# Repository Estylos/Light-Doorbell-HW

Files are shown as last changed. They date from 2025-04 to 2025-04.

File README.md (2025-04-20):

# Light Doorbell Hardware

This repository contains the KiCad design files (schematics and 4-layer circular PCB) for the Light Doorbell prototype: a **battery-powered, LED-signaling doorbell** based on a **STM32L051K8T6** microcontroller and **RFM69HCW** 433 MHz radio module.

A light doorbell is useful in many situations: notifying a user wearing headphones, assisting people with hearing impairments, or simply providing a silent visual alert...

## Overview

The prototype operates both as a transmitter and receiver.  
When the central button is pressed, it sends a coded message to another board listening on the same frequency. Upon receiving the message, the board flashes its dual-color LEDs, green or red, depending on the battery level.

The device is rechargeable via a USB-C connector, and works with a range of several tens of meters in open space.

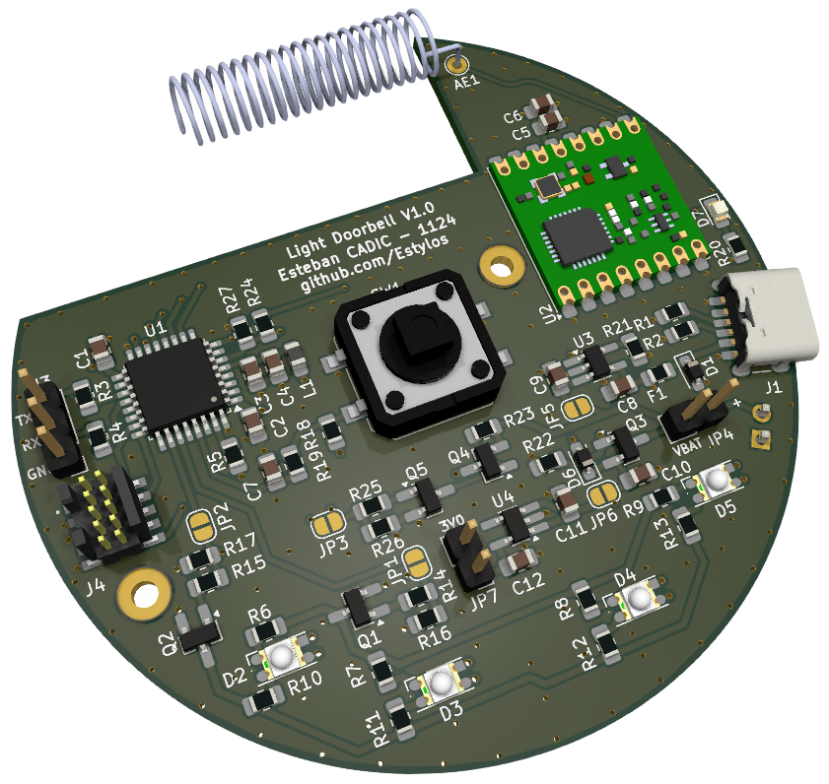
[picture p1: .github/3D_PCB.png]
PCB 3D view


## Features

- **Ultra-low-power STM32L051K8T6** ARM Cortex-M0+, 64 KB Flash, 8 KB RAM
- **RFM69HCW** 433 MHz transceiver module
- **Li-ion / Li-po battery** charger and management IC
- **3.0V LDO voltage regulator** to step down USB or battery voltage
- **Load sharing circuit** to seamlessly switch power source between USB and battery
- **Battery voltage monitoring**
- **433 MHz helical antenna**
- **Dual-color LEDs**, green and red for visual feedback
- **USB-C connector** for charging
- **Large mechanical push-button**
- **10-pin ARM SWD debug / programming port**
- **UART port** for optional serial communication
- **Multiple test points and jumpers** for current measurements, debug, and isolation
- Designed for **hand soldering** and **easy prototyping**
- Optimized for **low power consumption**

The current version focuses on development and testing. A future version could be further miniaturized by removing debug features and using smaller components...

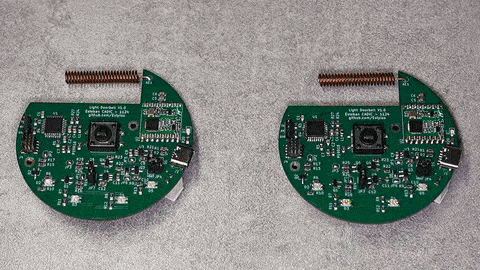
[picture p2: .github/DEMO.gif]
Demo GIF


## Related projects and documentation

- **[Light Doorbell SW](https://github.com/Estylos/Light-Doorbell-SW): Firmware of the project, based on the STM32 CubeHAL**  
- [STM32L051K8T6 Datasheet](https://www.st.com/en/microcontrollers-microprocessors/stm32l051k8.html)  
- [RFM69HCW Datasheet](https://cdn.sparkfun.com/datasheets/Wireless/General/RFM69HCW-V1.1.pdf)  
- [Adafruit Feather M0 Radio with RFM69 Packet Radio](https://learn.adafruit.com/adafruit-feather-m0-radio-with-rfm69-packet-radio/overview)  
- [Microchip (AN1149) - Designing A Li-Ion Battery Charger and Load Sharing System With Microchip’s Stand-Alone Li-Ion Battery Charge Management Controller](https://ww1.microchip.com/downloads/en/appnotes/01149c.pdf)  
- [Zak’s Electronics Blog - A Lithium Battery Charger with Load Sharing.](https://blog.zakkemble.net/a-lithium-battery-charger-with-load-sharing/)  
- [Hackaday - Embed with Elliot: Debounce your Noisy Buttons, Part I.](https://hackaday.com/2015/12/09/embed-with-elliot-debounce-your-noisy-buttons-part-i/)  
- [RefCircruit - Standard Simplest Battery Voltage Monitoring Circuit. ](https://refcircuit.com/articles/854-standard-simplest-battery-voltage-monitoring-circuit-engineering-schematic-solutions.html)

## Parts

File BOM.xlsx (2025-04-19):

Reference | Value | LCSC | Footprint | Description | Datasheet | Qty
AE1 | Antenna | C718844 | PRJ_FOOTPRINTS:THTPad_D2.0mm_Drill1.0mm | Spring Antenna 433 MHz | ~ | 1
C1,C2,C3,C5 | 100n | C1711 | PRJ_FOOTPRINTS:C_0805_2012Metric_Pad1.18x1.45mm_HandSolder | Unpolarized capacitor | ~ | 4
C4,C7,C10,C11 | 1u | C2798196 | PRJ_FOOTPRINTS:C_0805_2012Metric_Pad1.18x1.45mm_HandSolder | Unpolarized capacitor | ~ | 4
C6,C12 | 10u | C17024 | PRJ_FOOTPRINTS:C_0805_2012Metric_Pad1.18x1.45mm_HandSolder | Unpolarized capacitor | ~ | 2
C8,C9 | 4.7u | C1779 | PRJ_FOOTPRINTS:C_0805_2012Metric_Pad1.18x1.45mm_HandSolder | Unpolarized capacitor | ~ | 2
D1 | D_TVS_UNI | C552583 | PRJ_FOOTPRINTS:D_SOD-323_HandSoldering | Uni ESD protection PESD5V0U1UA,115, 6.8V Vbr, IEC61000−4−2 Level 4 | https://assets.nexperia.com/documents/data-sheet/PESD5V0U1UA.pdf | 1
D2,D3,D4,D5 | LED_Dual_Kingbright | C598328 | PRJ_FOOTPRINTS:LED_Kingbright_KPBD-3224 | Dual LED, red, green-yellow, 20°, SMD | https://www.lcsc.com/datasheet/lcsc_datasheet_2008121136_Kingbright-KPBD-3224SURKCGKC_C598328.pdf | 4
D6 | D_Schottky_BAT20JFILM | C155590 | PRJ_FOOTPRINTS:D_SOD-323_HandSoldering | Schottky diode, ST BAT20JFILM, 1A If, 23V Vrrm | https://eu.mouser.com/datasheet/2/389/bat20j-1849045.pdf | 1
D7 | LED | C434431 | PRJ_FOOTPRINTS:LED_0805_2012Metric_Pad1.15x1.40mm_HandSolder | Light emitting diode | ~ | 1
F1 | 0.5A | C2892412 | PRJ_FOOTPRINTS:Fuse_0805_2012Metric_Pad1.15x1.40mm_HandSolder | Fuse 0.5A, KUU K0805L050BR, 0805 | https://www.lcsc.com/datasheet/lcsc_datasheet_2109071730_KUU-K0805L050BR_C2892412.pdf | 1
J1 | USB_C_Receptacle_PowerOnly_6P | C668623 | PRJ_FOOTPRINTS:USB_C_Receptacle_GCT_USB4125-xx-x_6P_TopMnt_Horizontal | USB Power-Only 6P Type-C Receptacle connector | https://www.lcsc.com/datasheet/lcsc_datasheet_2006181823_SHOU-HAN-TYPE-C-6P-073_C668623.pdf | 1
J2 | Conn_01x02_Socket | C131337 | PRJ_FOOTPRINTS:PinHeader_1x02_P2.54mm_Vertical | Generic connector, single row, 01x02, script generated | ~ | 1
J3 | Conn_01x03_Pin |  | PRJ_FOOTPRINTS:PinHeader_1x03_P2.54mm_Vertical | Generic connector, single row, 01x03, script generated | ~ | 1
J4 | Conn_ARM_JTAG_SWD_10 | C448647 | PRJ_FOOTPRINTS:FTSH-105-01-L-DV-K | Cortex Debug Connector, standard ARM Cortex-M SWD and JTAG interface | http://infocenter.arm.com/help/topic/com.arm.doc.ddi0314h/DDI0314H_coresight_components_trm.pdf | 1
JP4,JP7 | Jumper_2_Bridged |  | PRJ_FOOTPRINTS:PinHeader_1x02_P2.54mm_Vertical | Jumper, 2-pole, closed/bridged | ~ | 2
L1 | L_Ferrite | C85835 | PRJ_FOOTPRINTS:L_0805_2012Metric_Pad1.05x1.20mm_HandSolder | Ferrite Beads, 280mΩ ±25%, 1kΩ@100MHz, 0805 | ~ | 1
Q1,Q2,Q5 | IRLML2502TRPBF | C2589 | PRJ_FOOTPRINTS:SOT-23_Handsoldering | N-Channel MOSFET, 20V Vds, 4.2A Id, 45 mΩ Rds(on), SOT-23 | https://www.infineon.com/dgdl/irlml2502pbf-1.pdf?fileId=5546d462533600a4015356680e672608 | 3
Q3,Q4 | IRLML6402TRPBF | C2593 | PRJ_FOOTPRINTS:SOT-23_Handsoldering | P-Channel MOSFET, -20V Vds, -3.7A Id, 65mΩ Rds(on), SOT-23 | https://www.infineon.com/dgdl/irlml6402pbf.pdf?fileId=5546d462533600a401535668d5c2263c | 2
R1,R2 | 5.1k | C2930296 | PRJ_FOOTPRINTS:R_0805_2012Metric_Pad1.20x1.40mm_HandSolder | Resistor | ~ | 2
R3,R4,R14,R15,R20,R25 | 470R | C2907329 | PRJ_FOOTPRINTS:R_0805_2012Metric_Pad1.20x1.40mm_HandSolder | Resistor | ~ | 6
R5,R16,R17,R22,R23,R26 | 100k | C25611 | PRJ_FOOTPRINTS:R_0805_2012Metric_Pad1.20x1.40mm_HandSolder | Resistor | ~ | 6
R6,R7,R8,R9,R10,R11,R12,R13 | 50R | C2828866 | PRJ_FOOTPRINTS:R_0805_2012Metric_Pad1.20x1.40mm_HandSolder | Resistor | ~ | 8
R18,R19,R21,R27 | 10k | C17414 | PRJ_FOOTPRINTS:R_0805_2012Metric_Pad1.20x1.40mm_HandSolder | Resistor | ~ | 4
R24 | 5k | C2828783 | PRJ_FOOTPRINTS:R_0805_2012Metric_Pad1.20x1.40mm_HandSolder | Resistor | ~ | 1
SW1 | SW_Push | C455234 | PRJ_FOOTPRINTS:SW_Push | Push button switch, generic, two pins | https://www.lcsc.com/datasheet/lcsc_datasheet_1912111437_XUNPU-TS-1003ST-26_C455234.pdf | 1
TP_3V0_1,TP_GRN_EN_1,TP_MCU_NRST_1,TP_RADIO_DI0_1,TP_RADIO_RST_1,TP_RED_EN_1,TP_SPI_MISO_1,TP_SPI_MOSI_1,TP_SPI_NSS_1,TP_SPI_SCK_1,TP_VBAT_1,TP_VBAT_ADC_1,TP_VBAT_EN_1,TP_VBUS_1,TP_VCC_1 | TestPoint |  | PRJ_FOOTPRINTS:TestPoint_Pad_D2.0mm | test point | ~ | 15
U1 | STM32L051K8T6 | C915970 | PRJ_FOOTPRINTS:LQFP-32_7x7mm_P0.8mm | STMicroelectronics Arm Cortex-M0+ MCU, 32-64KB flash, 8KB RAM, 32 MHz, 1.65-3.6V, 25 GPIO, LQFP32 | https://eu.mouser.com/datasheet/2/389/stm32l051c6-1851259.pdf | 1
U2 | RFM69HCW |  | PRJ_FOOTPRINTS:HOPERF_RFM9CW_SMD | ISM radio transceiver, SoM | https://cdn.sparkfun.com/datasheets/Wireless/General/RFM69HCW-V1.1.pdf | 1
U3 | MCP73831 | C424093 | PRJ_FOOTPRINTS:TSOT-23-5_HandSoldering | Single cell Li-Ion/Li-Po charge management controller, 4.20V, SOT23-5 | https://ww1.microchip.com/downloads/en/DeviceDoc/MCP73831-Family-Data-Sheet-DS20001984H.pdf | 1
U4 | TPS7A2030PDBVR | C963429 | PRJ_FOOTPRINTS:TSOT-23-5_HandSoldering | LDO Voltage Regulators, 300-mA, ultra-low-noise, low-IQ, SOT23-5 | https://www.ti.com/lit/ds/symlink/tps7a20.pdf | 1

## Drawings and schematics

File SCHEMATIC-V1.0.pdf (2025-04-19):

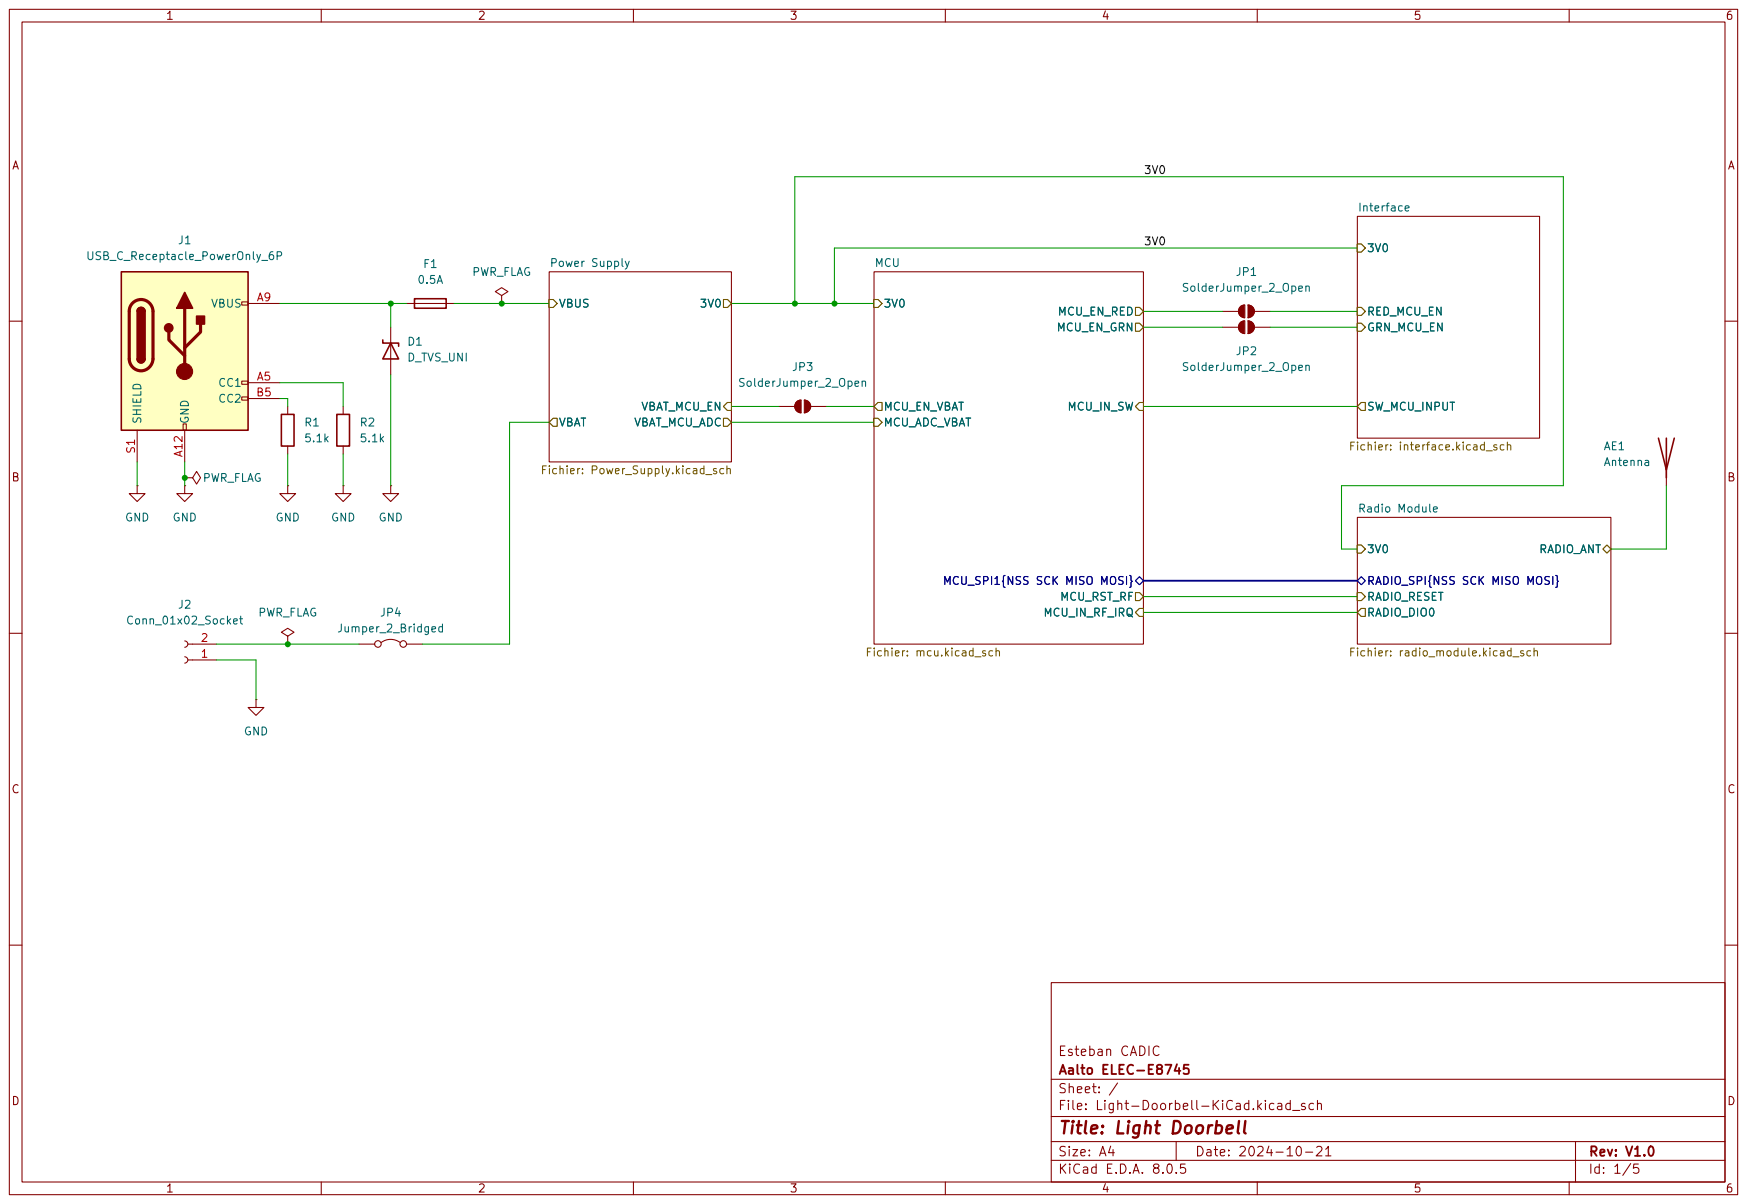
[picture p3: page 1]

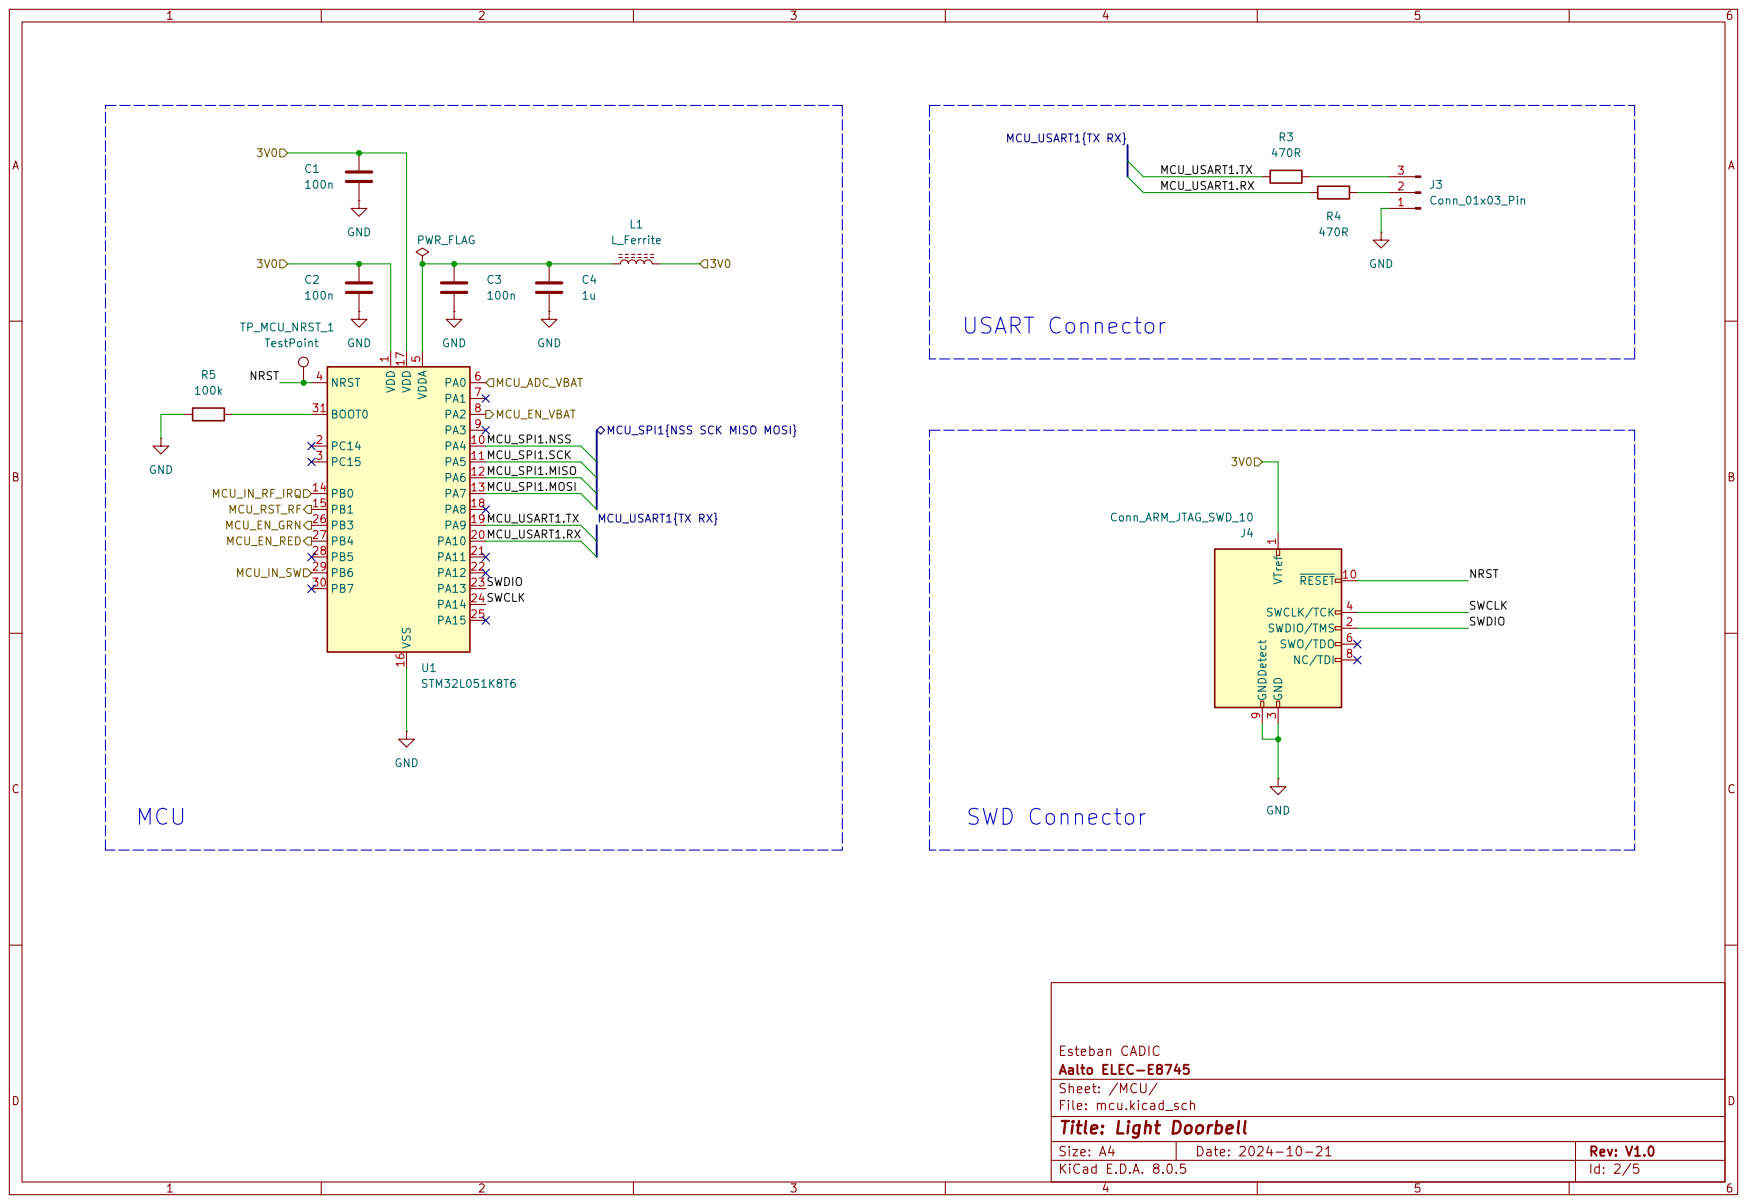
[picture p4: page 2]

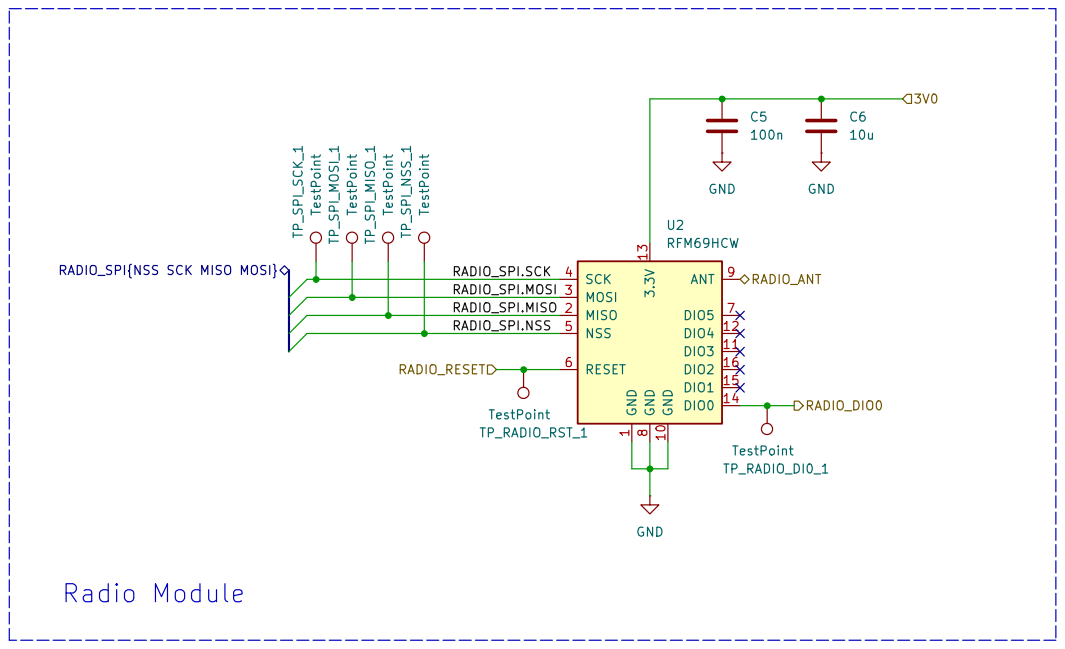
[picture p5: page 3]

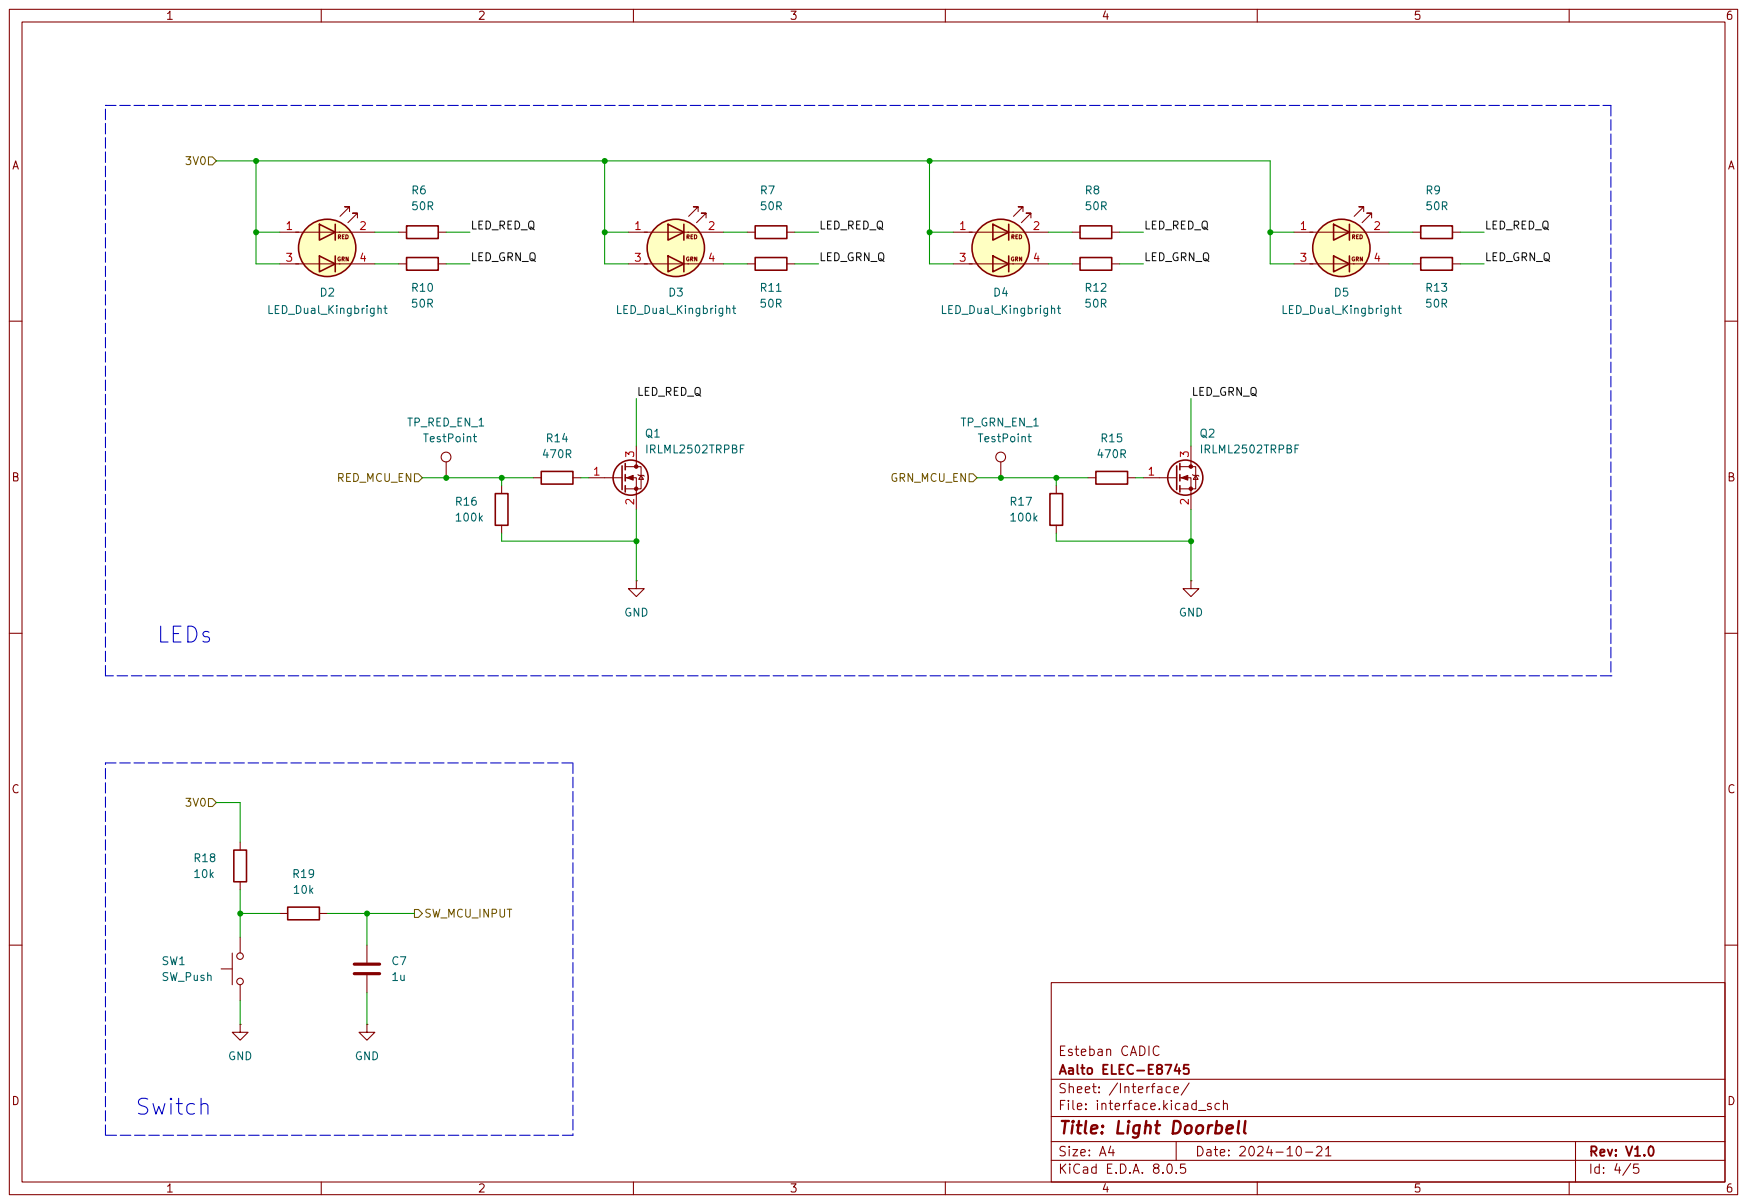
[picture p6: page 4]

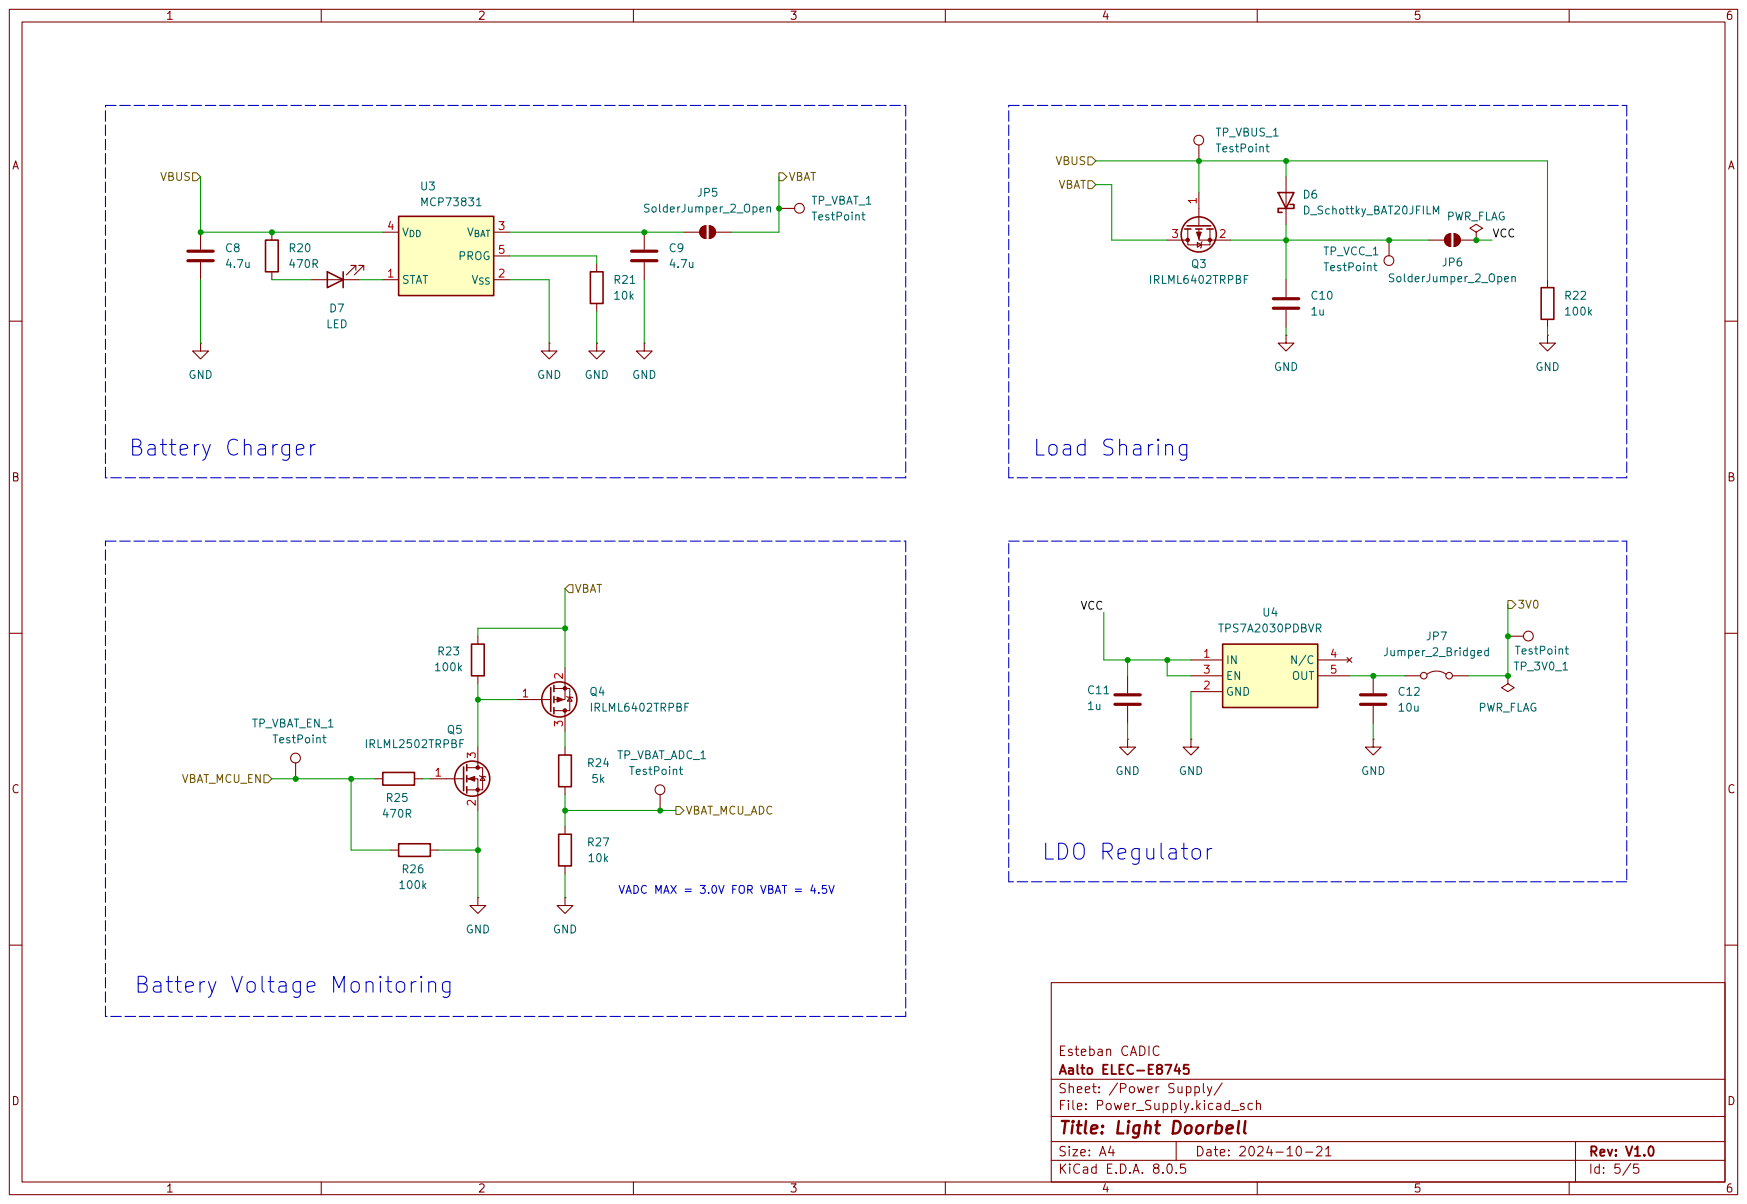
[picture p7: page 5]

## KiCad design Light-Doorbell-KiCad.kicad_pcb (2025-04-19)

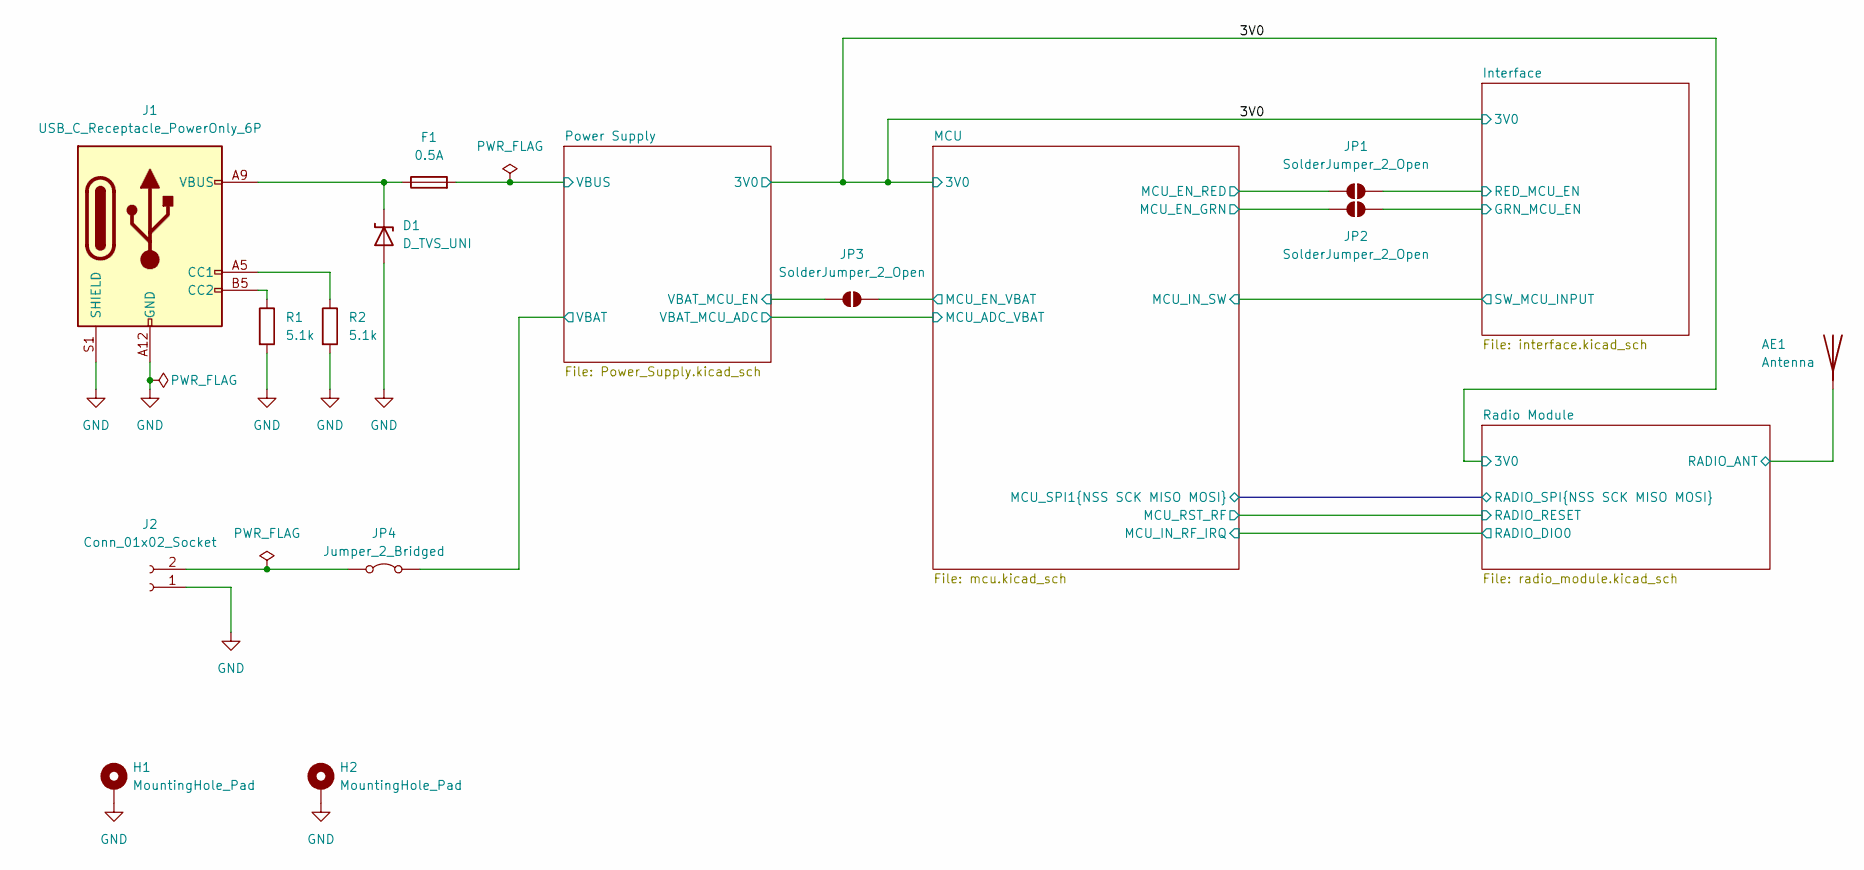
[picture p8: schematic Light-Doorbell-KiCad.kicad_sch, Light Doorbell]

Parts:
AE1: Antenna; THTPad_D2.0mm_Drill1.0mm; LCSC C718844
D1: D_TVS_UNI; D_SOD-323_HandSoldering; LCSC C552583
F1: 0.5A; Fuse_0805_2012Metric_Pad1.15x1.40mm_HandSolder; LCSC C2892412
H1, H2: MountingHole_Pad; MountingHole_2.2mm_M2_Pad
J1: USB_C_Receptacle_PowerOnly_6P; USB_C_Receptacle_GCT_USB4125-xx-x_6P_TopMnt_Horizontal; LCSC C668623
J2: Conn_01x02_Socket; PinHeader_1x02_P2.54mm_Vertical; LCSC C131337
JP1, JP2, JP3: SolderJumper_2_Open; SolderJumper-2_P1.3mm_Open_RoundedPad1.0x1.5mm
JP4: Jumper_2_Bridged; PinHeader_1x02_P2.54mm_Vertical
R1, R2: 5.1k; R_0805_2012Metric_Pad1.20x1.40mm_HandSolder; LCSC C2930296

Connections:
/Interface/GRN_MCU_EN: JP2.2 (B); also elsewhere on the board
/Interface/RED_MCU_EN: JP1.2 (B); also elsewhere on the board
/MCU/MCU_EN_GRN: JP2.1 (A); also elsewhere on the board
/MCU/MCU_EN_RED: JP1.1 (A); also elsewhere on the board
/MCU/MCU_EN_VBAT: JP3.2 (B); also elsewhere on the board
/Power Supply/VBAT: JP4.2 (B); also elsewhere on the board
/Power Supply/VBAT_MCU_EN: JP3.1 (A); also elsewhere on the board
/Power Supply/VBUS: F1.2; also elsewhere on the board
/Radio Module/RADIO_ANT: AE1.1 (A); also elsewhere on the board
GND: D1.2 (A2), H1.1, H2.1, J1.A12 (GND), J1.B12 (GND), J1.S1 (SHIELD), J2.1, R1.2, R2.2; also elsewhere on the board
unnamed: D1.1 (A1), F1.1, J1.A9 (VBUS), J1.B9 (VBUS)
unnamed: J1.A5 (CC1), R2.1
unnamed: J1.B5 (CC2), R1.1
unnamed: J2.2, JP4.1 (A)

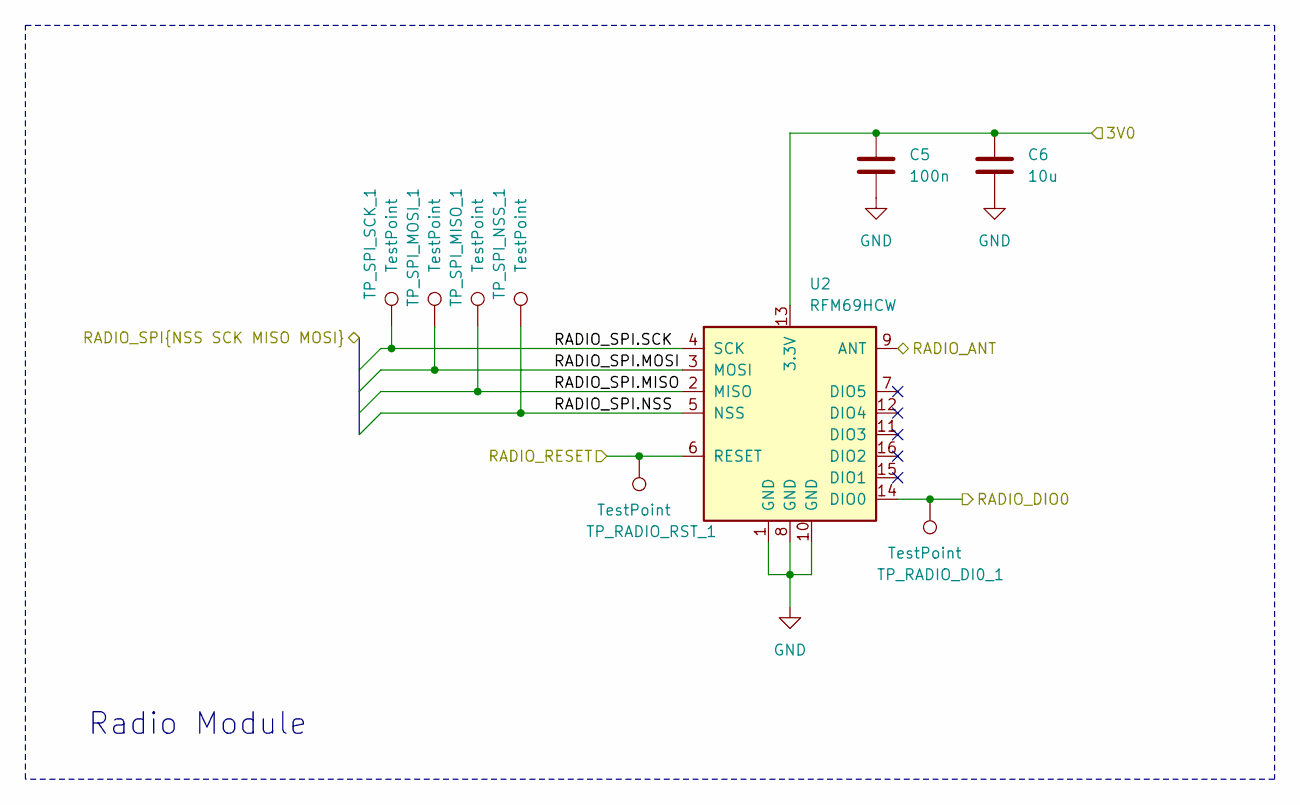
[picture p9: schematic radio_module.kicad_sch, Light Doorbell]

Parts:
C5: 100n; C_0805_2012Metric_Pad1.18x1.45mm_HandSolder; LCSC C1711
C6: 10u; C_0805_2012Metric_Pad1.18x1.45mm_HandSolder; LCSC C17024
TP_RADIO_DI0_1: TestPoint; TestPoint_Pad_D2.0mm
TP_RADIO_RST_1: TestPoint; TestPoint_Pad_D2.0mm
TP_SPI_MISO_1: TestPoint; TestPoint_Pad_D2.0mm
TP_SPI_MOSI_1: TestPoint; TestPoint_Pad_D2.0mm
TP_SPI_NSS_1: TestPoint; TestPoint_Pad_D2.0mm
TP_SPI_SCK_1: TestPoint; TestPoint_Pad_D2.0mm
U2: RFM69HCW; HOPERF_RFM9CW_SMD

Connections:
/3V0: C5.1, C6.1, U2.13 (3.3V); also elsewhere on the board
/MCU/MCU_IN_RF_IRQ: TP_RADIO_DI0_1.1, U2.14 (DIO0); also elsewhere on the board
/MCU/MCU_RST_RF: TP_RADIO_RST_1.1, U2.6 (RESET); also elsewhere on the board
/MCU/MCU_SPI1.MISO: TP_SPI_MISO_1.1, U2.2 (MISO); also elsewhere on the board
/MCU/MCU_SPI1.MOSI: TP_SPI_MOSI_1.1, U2.3 (MOSI); also elsewhere on the board
/MCU/MCU_SPI1.NSS: TP_SPI_NSS_1.1, U2.5 (NSS); also elsewhere on the board
/MCU/MCU_SPI1.SCK: TP_SPI_SCK_1.1, U2.4 (SCK); also elsewhere on the board
/Radio Module/RADIO_ANT: U2.9 (ANT); also elsewhere on the board
GND: C5.2, C6.2, U2.1 (GND), U2.8 (GND), U2.10 (GND); also elsewhere on the board

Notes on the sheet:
Radio Module

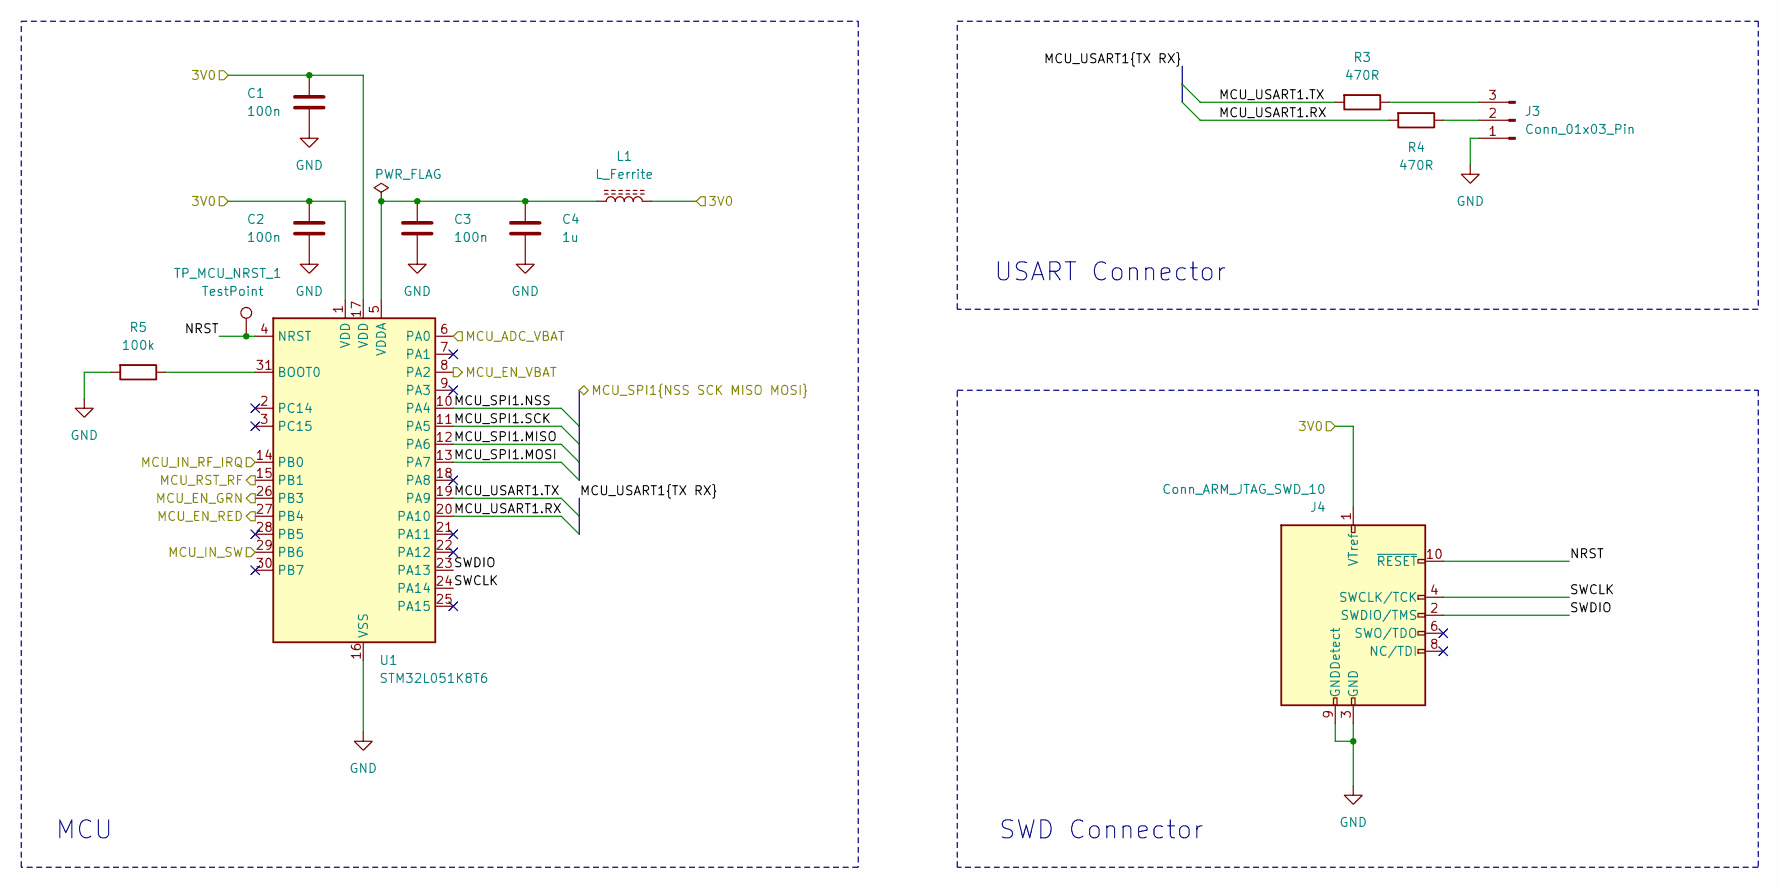
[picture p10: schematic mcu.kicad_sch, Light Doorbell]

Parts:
C1, C2, C3: 100n; C_0805_2012Metric_Pad1.18x1.45mm_HandSolder; LCSC C1711
C4: 1u; C_0805_2012Metric_Pad1.18x1.45mm_HandSolder; LCSC C2798196
J3: Conn_01x03_Pin; PinHeader_1x03_P2.54mm_Vertical
J4: Conn_ARM_JTAG_SWD_10; FTSH-105-01-L-DV-K; LCSC C448647
L1: L_Ferrite; L_0805_2012Metric_Pad1.05x1.20mm_HandSolder; LCSC C85835
R3, R4: 470R; R_0805_2012Metric_Pad1.20x1.40mm_HandSolder; LCSC C2907329
R5: 100k; R_0805_2012Metric_Pad1.20x1.40mm_HandSolder; LCSC C25611
TP_MCU_NRST_1: TestPoint; TestPoint_Pad_D2.0mm
U1: STM32L051K8T6; LQFP-32_7x7mm_P0.8mm; LCSC C915970

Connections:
/3V0: C1.1, C2.1, J4.1 (VTref), L1.2, U1.1 (VDD), U1.17 (VDD); also elsewhere on the board
/Interface/SW_MCU_INPUT: U1.29 (PB6); also elsewhere on the board
/MCU/MCU_ADC_VBAT: U1.6 (PA0); also elsewhere on the board
/MCU/MCU_EN_GRN: U1.26 (PB3); also elsewhere on the board
/MCU/MCU_EN_RED: U1.27 (PB4); also elsewhere on the board
/MCU/MCU_EN_VBAT: U1.8 (PA2); also elsewhere on the board
/MCU/MCU_IN_RF_IRQ: U1.14 (PB0); also elsewhere on the board
/MCU/MCU_RST_RF: U1.15 (PB1); also elsewhere on the board
/MCU/MCU_SPI1.MISO: U1.12 (PA6); also elsewhere on the board
/MCU/MCU_SPI1.MOSI: U1.13 (PA7); also elsewhere on the board
/MCU/MCU_SPI1.NSS: U1.10 (PA4); also elsewhere on the board
/MCU/MCU_SPI1.SCK: U1.11 (PA5); also elsewhere on the board
/MCU/MCU_USART1.RX: R4.2, U1.20 (PA10)
/MCU/MCU_USART1.TX: R3.2, U1.19 (PA9)
/MCU/NRST: J4.10 (~RESET), TP_MCU_NRST_1.1, U1.4 (NRST)
/MCU/SWCLK: J4.4 (SWCLK/TCK), U1.24 (PA14)
/MCU/SWDIO: J4.2 (SWDIO/TMS), U1.23 (PA13)
GND: C1.2, C2.2, C3.2, C4.2, J3.1, J4.3 (GND), J4.5 (GND), J4.9 (GNDDetect), R5.2, U1.16 (VSS), U1.32 (VSS); also elsewhere on the board
unnamed: J3.2, R4.1
unnamed: J3.3, R3.1
unnamed: R5.1, U1.31 (BOOT0)
unnamed: C3.1, C4.1, L1.1, U1.5 (VDDA)

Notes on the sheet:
USART Connector
MCU
SWD Connector

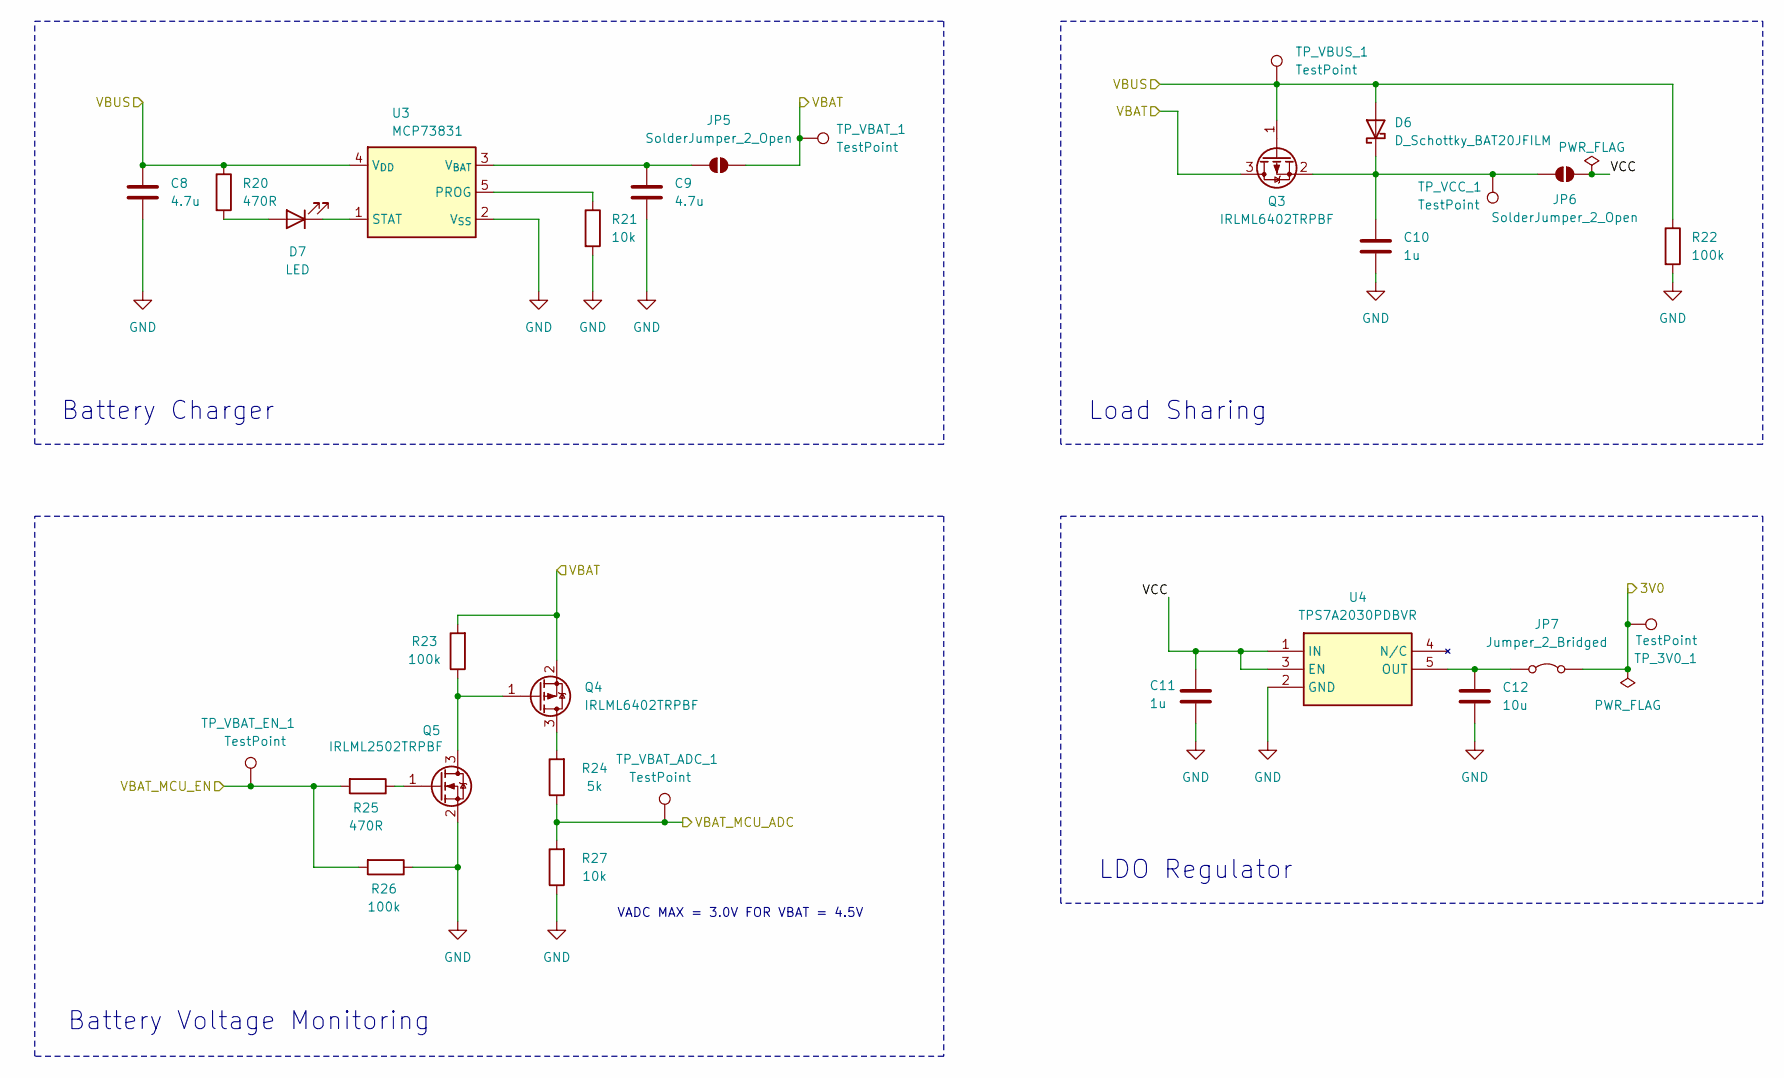
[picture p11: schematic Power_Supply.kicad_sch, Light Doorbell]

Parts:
C8, C9: 4.7u; C_0805_2012Metric_Pad1.18x1.45mm_HandSolder; LCSC C1779
C10, C11: 1u; C_0805_2012Metric_Pad1.18x1.45mm_HandSolder; LCSC C2798196
C12: 10u; C_0805_2012Metric_Pad1.18x1.45mm_HandSolder; LCSC C17024
D6: D_Schottky_BAT20JFILM; D_SOD-323_HandSoldering; LCSC C155590
D7: LED; LED_0805_2012Metric_Pad1.15x1.40mm_HandSolder; LCSC C434431
JP5, JP6: SolderJumper_2_Open; SolderJumper-2_P1.3mm_Open_RoundedPad1.0x1.5mm
JP7: Jumper_2_Bridged; PinHeader_1x02_P2.54mm_Vertical
Q3, Q4: IRLML6402TRPBF; SOT-23_Handsoldering; LCSC C2593
Q5: IRLML2502TRPBF; SOT-23_Handsoldering; LCSC C2589
R20, R25: 470R; R_0805_2012Metric_Pad1.20x1.40mm_HandSolder; LCSC C2907329
R21, R27: 10k; R_0805_2012Metric_Pad1.20x1.40mm_HandSolder; LCSC C17414
R22, R23, R26: 100k; R_0805_2012Metric_Pad1.20x1.40mm_HandSolder; LCSC C25611
R24: 5k; R_0805_2012Metric_Pad1.20x1.40mm_HandSolder; LCSC C2828783
TP_3V0_1: TestPoint; TestPoint_Pad_D2.0mm
TP_VBAT_1: TestPoint; TestPoint_Pad_D2.0mm
TP_VBAT_ADC_1: TestPoint; TestPoint_Pad_D2.0mm
TP_VBAT_EN_1: TestPoint; TestPoint_Pad_D2.0mm
TP_VBUS_1: TestPoint; TestPoint_Pad_D2.0mm
TP_VCC_1: TestPoint; TestPoint_Pad_D2.0mm
U3: MCP73831; TSOT-23-5_HandSoldering; LCSC C424093
U4: TPS7A2030PDBVR; TSOT-23-5_HandSoldering; LCSC C963429

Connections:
/3V0: JP7.2 (B), TP_3V0_1.1; also elsewhere on the board
/MCU/MCU_ADC_VBAT: R24.1, R27.2, TP_VBAT_ADC_1.1; also elsewhere on the board
/Power Supply/VBAT: JP5.2 (B), Q3.3 (D), Q4.2 (S), R23.2, TP_VBAT_1.1; also elsewhere on the board
/Power Supply/VBAT_MCU_EN: R25.2, R26.2, TP_VBAT_EN_1.1; also elsewhere on the board
/Power Supply/VBUS: C8.1, D6.2 (A), Q3.1 (G), R20.1, R22.1, TP_VBUS_1.1, U3.4 (V_{DD}); also elsewhere on the board
/Power Supply/VCC: C11.1, JP6.2 (B), U4.1 (IN), U4.3 (EN)
GND: C8.2, C9.2, C10.2, C11.2, C12.2, Q5.2 (S), R21.2, R22.2, R26.1, R27.1, U3.2 (V_{SS}), U4.2 (GND); also elsewhere on the board
unnamed: C10.1, D6.1 (K), JP6.1 (A), Q3.2 (S), TP_VCC_1.1
unnamed: D7.2 (A), R20.2
unnamed: D7.1 (K), U3.1 (STAT)
unnamed: C9.1, JP5.1 (A), U3.3 (V_{BAT})
unnamed: C12.1, JP7.1 (A), U4.5 (OUT)
unnamed: Q4.3 (D), R24.2
unnamed: Q4.1 (G), Q5.3 (D), R23.1
unnamed: Q5.1 (G), R25.1
unnamed: R21.1, U3.5 (PROG)

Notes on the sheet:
Battery Voltage Monitoring
Load Sharing
Battery Charger
VADC MAX = 3.0V FOR VBAT = 4.5V
LDO Regulator

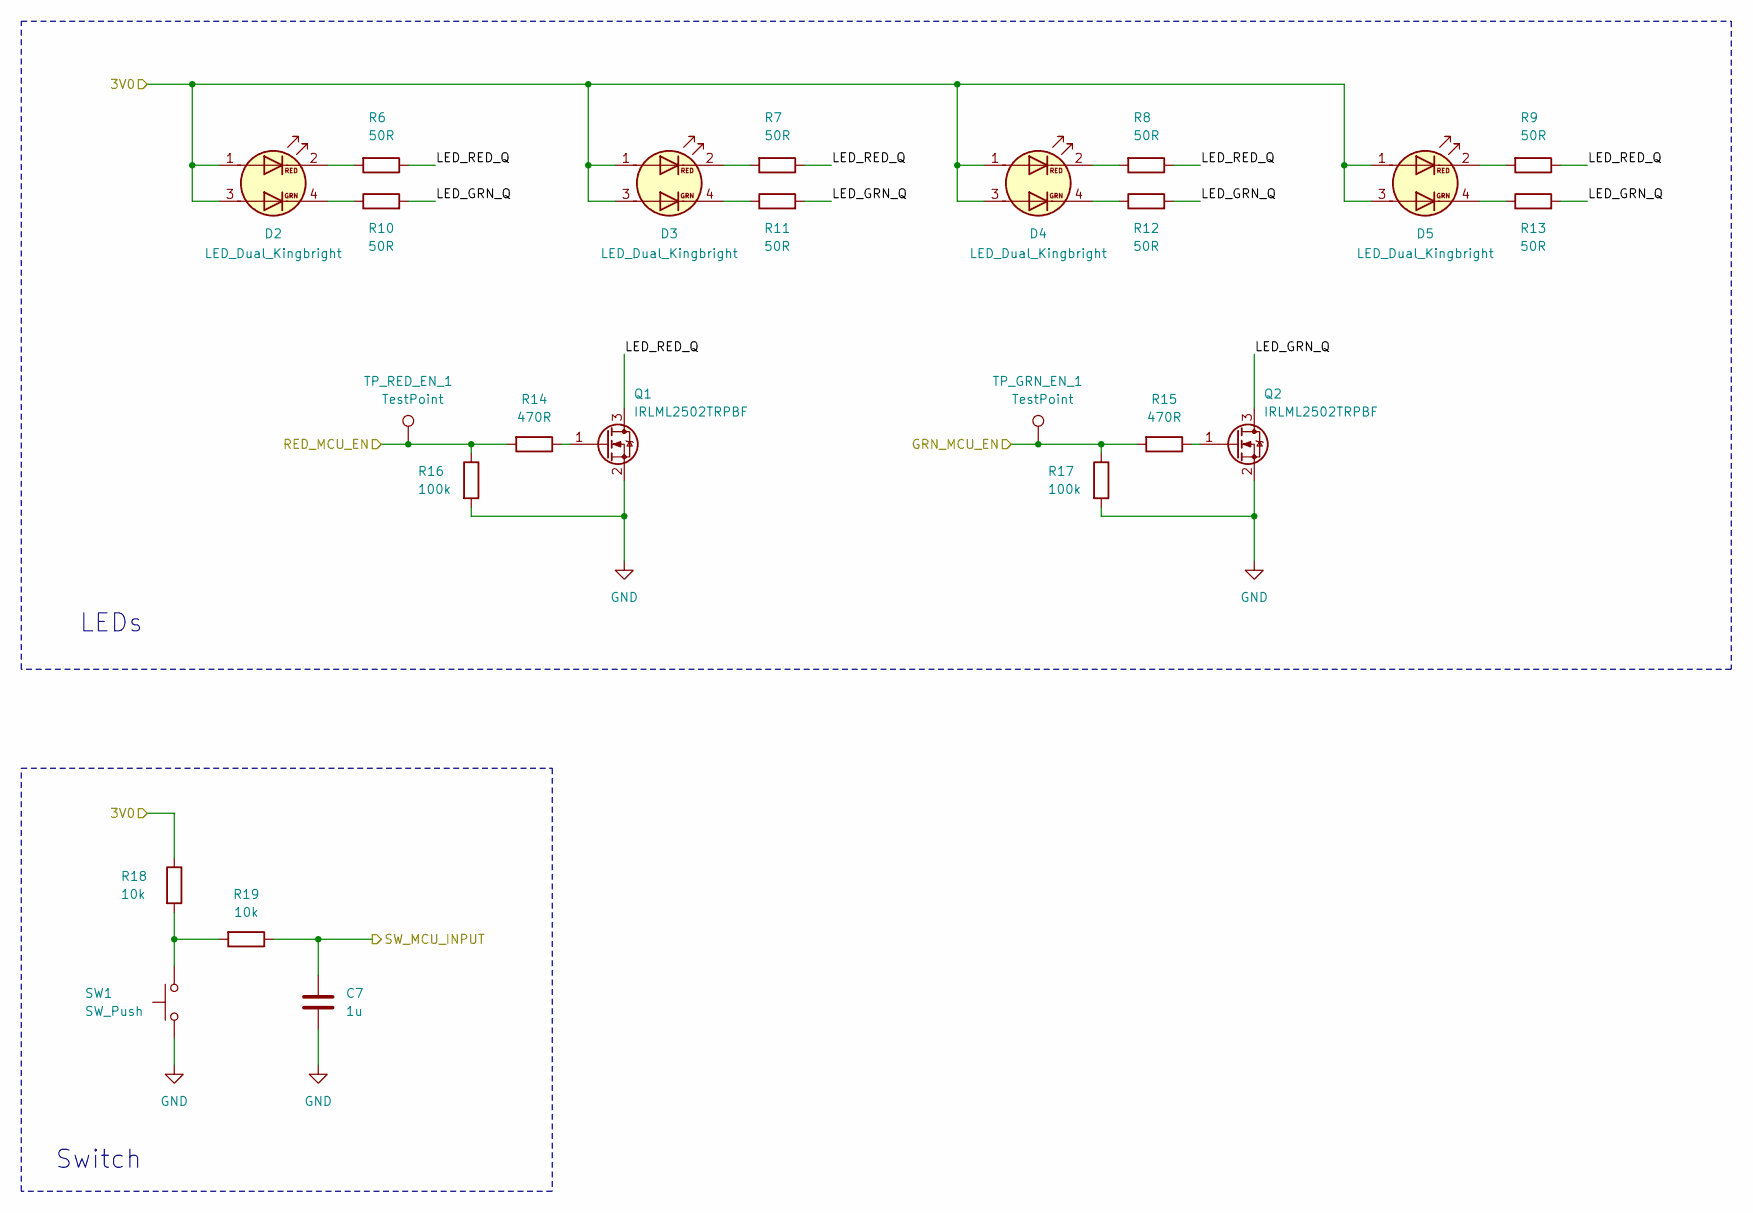
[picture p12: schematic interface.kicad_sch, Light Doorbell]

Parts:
C7: 1u; C_0805_2012Metric_Pad1.18x1.45mm_HandSolder; LCSC C2798196
D2, D3, D4, D5: LED_Dual_Kingbright; LED_Kingbright_KPBD-3224; LCSC C598328
Q1, Q2: IRLML2502TRPBF; SOT-23_Handsoldering; LCSC C2589
R6, R7, R8, R9, R10, R11, R12, R13: 50R; R_0805_2012Metric_Pad1.20x1.40mm_HandSolder; LCSC C2828866
R14, R15: 470R; R_0805_2012Metric_Pad1.20x1.40mm_HandSolder; LCSC C2907329
R16, R17: 100k; R_0805_2012Metric_Pad1.20x1.40mm_HandSolder; LCSC C25611
R18, R19: 10k; R_0805_2012Metric_Pad1.20x1.40mm_HandSolder; LCSC C17414
SW1: SW_Push; LCSC C455234
TP_GRN_EN_1: TestPoint; TestPoint_Pad_D2.0mm
TP_RED_EN_1: TestPoint; TestPoint_Pad_D2.0mm

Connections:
/3V0: D2.1 (A1), D2.3 (A2), D3.1 (A1), D3.3 (A2), D4.1 (A1), D4.3 (A2), D5.1 (A1), D5.3 (A2), R18.1; also elsewhere on the board
/Interface/GRN_MCU_EN: R15.2, R17.1, TP_GRN_EN_1.1; also elsewhere on the board
/Interface/LED_GRN_Q: Q2.3 (D), R10.2, R11.2, R12.2, R13.2
/Interface/LED_RED_Q: Q1.3 (D), R6.1, R7.1, R8.1, R9.1
/Interface/RED_MCU_EN: R14.2, R16.1, TP_RED_EN_1.1; also elsewhere on the board
/Interface/SW_MCU_INPUT: C7.1, R19.1; also elsewhere on the board
GND: C7.2, Q1.2 (S), Q2.2 (S), R16.2, R17.2, SW1.1; also elsewhere on the board
unnamed: D2.2 (K1), R6.2
unnamed: D2.4 (K2), R10.1
unnamed: D3.2 (K1), R7.2
unnamed: D3.4 (K2), R11.1
unnamed: D4.2 (K1), R8.2
unnamed: D4.4 (K2), R12.1
unnamed: D5.2 (K1), R9.2
unnamed: D5.4 (K2), R13.1
unnamed: Q1.1 (G), R14.1
unnamed: Q2.1 (G), R15.1
unnamed: R18.2, R19.2, SW1.2

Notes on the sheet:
Switch
LEDs

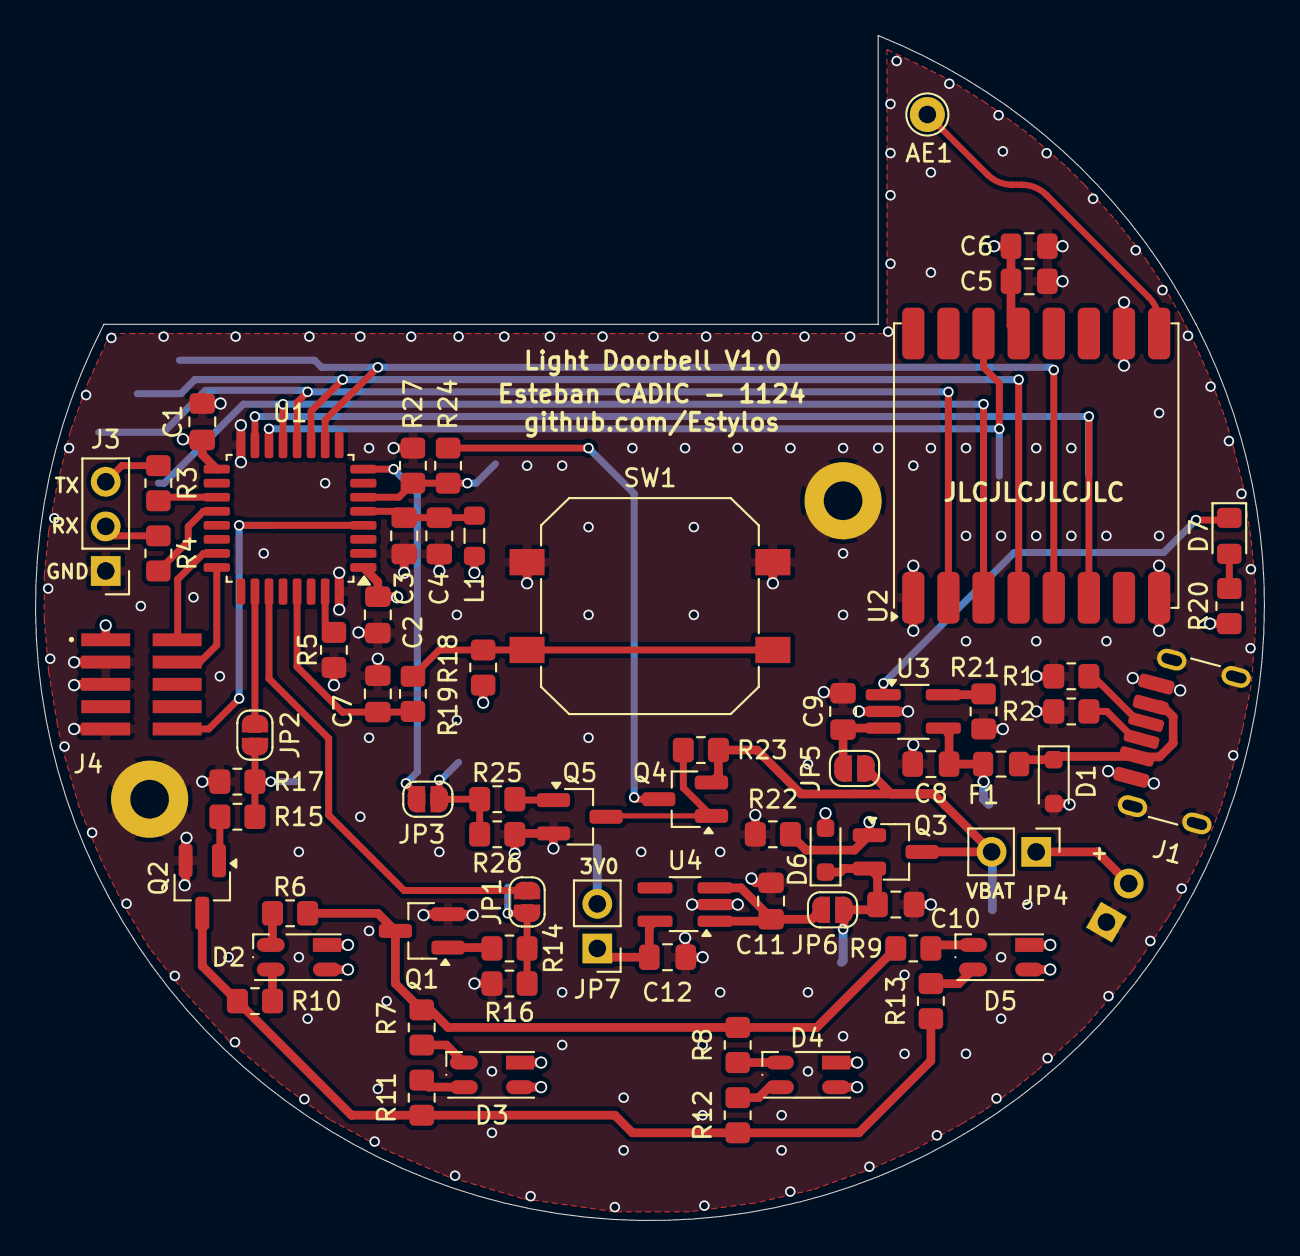
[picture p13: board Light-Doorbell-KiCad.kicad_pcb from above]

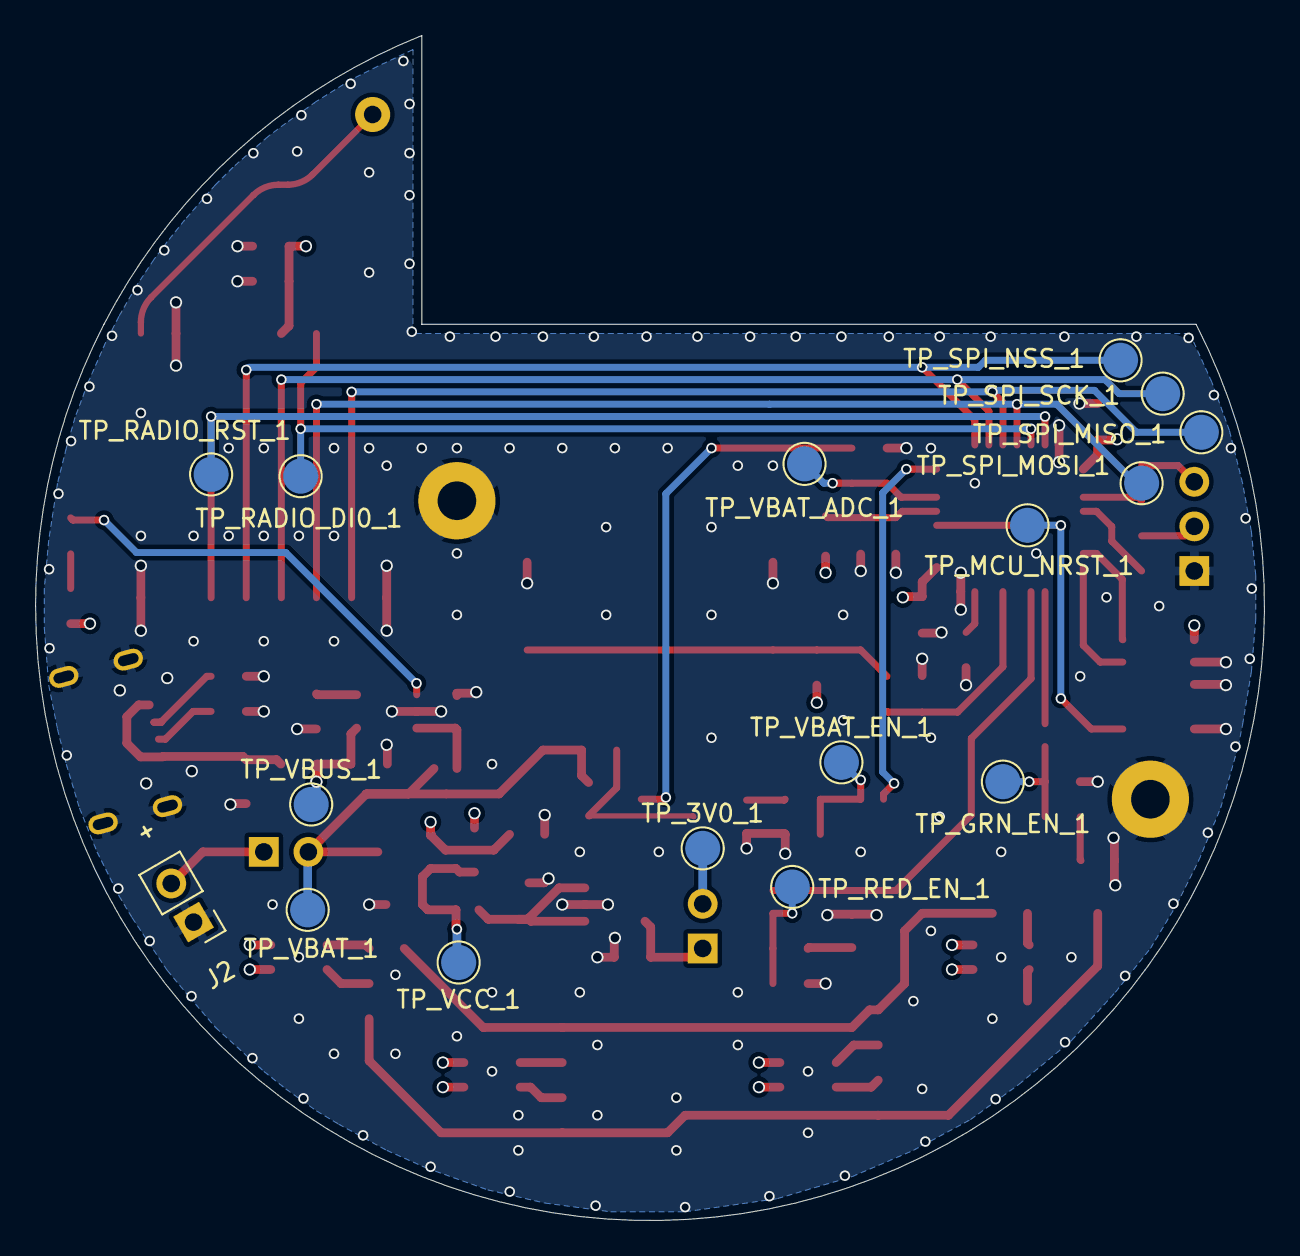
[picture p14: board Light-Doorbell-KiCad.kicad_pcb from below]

Board: 4 copper layers, 70.0 x 67.5 mm, 87 parts (16 on the bottom side), 55 nets.
